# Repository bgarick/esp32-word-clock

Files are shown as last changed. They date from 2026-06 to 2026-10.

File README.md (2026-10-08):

# ESP32 Word Clock

A handmade LED word clock built on an ESP32-C3, displaying time in natural language using 144 NeoPixel LEDs. Mounts vertically or horizontally. Colors shift by season and holiday automatically.

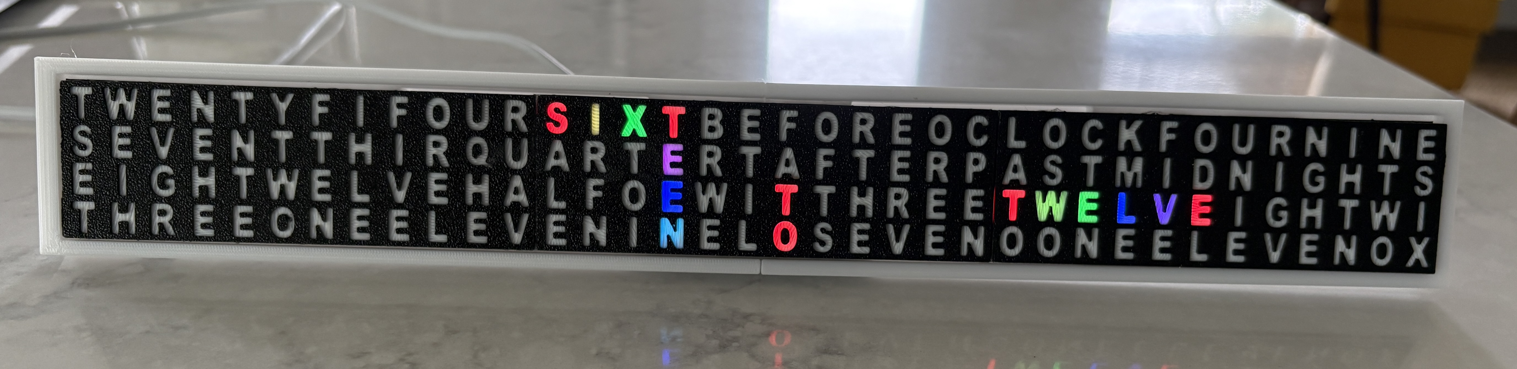
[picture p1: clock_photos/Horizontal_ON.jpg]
Word Clock


---

## How It Works

The clock displays time as words — *"TWENTY FIVE PAST THREE"* — lit across a custom 144-LED grid. The LED layout is unique: every minute of the day is represented by a specific combination of illuminated letters, in two orientations (vertical 4×36, horizontal 36×4) using the same physical LED strip.

Time is synced via NTP over Wi-Fi. Colors change automatically by season, with holiday overrides for Valentine's Day, St. Patrick's Day, July 4th, Halloween, Thanksgiving, and Christmas. June is Pride rainbow. April Fools' Day displays a random wrong time in a random palette every minute.

A configurable birthday date triggers rainbow mode on that day.

---

## Hardware

| Part | Detail |
|---|---|
| Microcontroller | ESP32-C3 Super Mini (no pins soldered — wires direct to board) |
| LED panels | 3× 4×12 NeoPixel panels (WS2812B), chained = 144 LEDs total |
| Data pin | GPIO 4 |
| Button pin | GPIO 9 (BOOT button) |
| Power | 5V via USB-C — standard adapter only, **no quick-charge** |
| 3D printed parts | See STL files in `/stl` |
| Other | Hookup wire, solder, thick clear glue (e.g. Gorilla Glue Clear) |

**Wiring:** 5V → LED 5V, GND → LED GND, GPIO 4 → LED Data In.

**Do not solder header pins to the ESP32-C3.** Solder wires directly into the through-holes. On vertical builds, solder from the back of the board. On horizontal builds, solder from the front.

---

## LED Panels & Addressing

The three 4×12 NeoPixel panels are chained together and addressed by the ESP32-C3 as a single continuous 144-LED array (LED 0–143). No special configuration is needed beyond `NUMPIXELS 144` in the code — the panels are transparent to the firmware.

Each panel has a data-in connector on one end and data-out on the other, with arrows on the PCB showing the LED data flow direction (boustrophedon — snaking back and forth across rows). Chain them so data flows continuously from panel 1 through panel 3.

**LED 0 location:**
- **Vertical:** bottom-right of the assembled clock
- **Horizontal:** top-right of the assembled clock

The mounting clips on the panels must be removed before fitting them into the word panel pockets — they take up too much space. After removing clips, solder the panels together: Data Out of panel 1 → Data In of panel 2, and so on. Solder 5V and GND in parallel across all three panels.

---

## 3D Printed Parts

Each orientation has its own set of STL files.

### Vertical
| File | Description |
|---|---|
| `v_panel_1.stl` | Word panel 1 of 3 |
| `v_panel_2.stl` | Word panel 2 of 3 |
| `v_panel_3.stl` | Word panel 3 of 3 |
| `v_base.stl` | Back panel |

### Horizontal
| File | Description |
|---|---|
| `h_panel_1.stl` | Word panel 1 of 3 |
| `h_panel_2.stl` | Word panel 2 of 3 |
| `h_panel_3.stl` | Word panel 3 of 3 |
| `h_base.stl` | Base panel |
| `h_base_3.stl` | Stand |

The base parts are single-piece designs. If they exceed your printer's build volume, split them in your slicer before printing and glue the pieces together. The horizontal stand (`h_base_3`) attaches to the base with a flat glue joint.

---

## Printing the Word Panels

The word panels are the trickiest part. Each panel has letters on the front face and a grid of LED pockets on the back that the LED panels seat into.

**Print face down** (letters on the bed). No supports needed.

### Color Change Sequence
The panels require two filament color changes:

1. **Black** — letters print first, face down on the bed
2. **White** — flat backing layer; this is the light diffuser that lets LED glow through the letters while blocking bleed between them
3. **Black** — final top layer(s) seal the back and prevent light bleed around the outside

The exact layer numbers depend on your slicer settings and layer height. Preview in your slicer before printing — you're looking for the transition where the letters end, the flat diffuser layer begins, and then the solid back begins. See **clock_photos/Print_Detail.jpg**

The base parts print in black only — no color change needed.

### Glue
Use a thick, non-runny clear adhesive (Gorilla Glue Clear works well). Runny glues will wick into the LED pockets and onto the LEDs. Glue is used for all joints: LED panels into word panel pockets, word panels to each other, word panel assembly to base, and base to stand.

---

## Classic ESP32 (Dev Module) Build

The same source also builds for a classic ESP32 dev board (the original, non-C3 design). The right image is chosen by the board you compile for, and each chip auto-updates from its own binary.

| | ESP32-C3 | Classic ESP32 |
|---|---|---|
| Arduino board | ESP32C3 Dev Module | ESP32 Dev Module |
| LED data pin | GPIO 4 | GPIO 4 (default, selectable) |
| Button pin | GPIO 9 | GPIO 0 (BOOT) |
| Release file | `esp32-word-clock.bin` | `esp32-word-clock-esp32.bin` |

**Easiest install:** open the installer page, click the button for your board, and pick the serial port. A normal install keeps WiFi/timezone settings.

**LED stays dark?** On the classic ESP32 the data pin can be changed without reflashing: hold BOOT while powering on, join the `Word Clock Setup` WiFi network, pick the correct *LED Data Pin*, and save. The clock restarts on the new pin. The picker only offers GPIOs that are safe for NeoPixel data (not flash, input-only, or boot-strapping pins).

**Manual flashing:** the release also includes `esp32-word-clock-esp32-full.bin`, a single merged image to write at address `0x0` with esptool or the Espressif Flash Download Tool.

---

## ESP32-C3 Mounting

The ESP32-C3 sits in a dedicated pocket in the base. **Orient it carefully before gluing** — the BOOT button must align with the access hole and the USB-C port must remain accessible. Once glued there is no repositioning it.

- **Horizontal:** ESP32-C3 pocket is inside the base housing, board tucked in with wires soldered from the front
- **Vertical:** ESP32-C3 pocket is on the outside back of the base, more exposed, with the button hole above it and wires soldered from the back of the board

---

## Test Before You Glue

**Do this before any permanent assembly.**

Wire up the chained LED panels to the ESP32-C3. Flash the included test sketch for your orientation — `Horizontal_Word_Test.ino` or `Vertical_Word_Test.ino`. Each sketch cycles through every defined word, lighting the correct LEDs for one second each and printing the word name and LED indices to Serial.

Verify every word lights up in the right position on the physical panels before proceeding. Once the LED panels are glued into the word panel pockets there is no going back without damage.

---

## Assembly Order

1. **Print word panels** — black/white/black color change, face down, no supports
2. **Print base panels** — black only; split in slicer if needed for your print bed
3. **Prep LED panels** — remove mounting clips, solder panels into a chain, solder leads to ESP32-C3
4. **Test** — flash the appropriate word test sketch, verify all words light up correctly
5. **Seat LEDs** — press LED panels into the pockets on the back of the word panels, glue in place
6. **Join word panels** — glue the three word panels together into a single strip
7. **Mount ESP32-C3** — orient carefully so BOOT button and USB-C align with access points, glue in place
8. **Attach base** — glue base to the back of the word panel assembly
9. **Horizontal only** — glue stand (`h_base_3`) to base with flat joint

---

## Software Setup

### Arduino IDE Board Settings
- Board: **ESP32C3 Dev Module**
- USB CDC On Boot: **Enabled** (required for Serial monitor)

### Libraries Required
- `WiFiManager` (tzapu)
- `Adafruit NeoPixel`
- `Preferences` (built-in ESP32)

### First Upload
1. Clone or download this repo
2. Open `esp32-word-clock.ino` in Arduino IDE
3. Select correct board and port
4. Upload

---

## First-Time Setup

On first power-up the clock broadcasts a Wi-Fi network called **Word Clock Setup**.

1. Connect your phone to **Word Clock Setup** (no password) — see **clock_photos/WiFi_Config.png**
2. The setup portal opens automatically — or go to `192.168.4.1`
3. Select your Wi-Fi network and enter password
4. Choose your **timezone** (US only: Eastern, Central, Mountain, Pacific, Alaska, Hawaii)
5. Choose **layout** (Vertical or Horizontal — must match your physical build)
6. Set your **birthday month/day** for rainbow mode on that date
7. Save — clock restarts and displays correct time within 30 seconds

**2.4 GHz only.** If your router shares a name for both bands, separate them in router settings.

---

## The Setup Button

There's a small hole on the back near the USB-C port. Use a straightened wire to press the button through it.

| Action | Result |
|---|---|
| Press at any time | Reopens setup portal |
| Hold 5 seconds at startup | Clears saved Wi-Fi credentials |

---

## Color Palettes

> Note: Photos in `clock_photos/` were taken in June — colors shown are Pride Month rainbow mode.

| Period / Holiday | Colors |
|---|---|
| Winter (Dec 22 – Mar) | Blues |
| Spring (Mar – Jun) | Pinks, yellows |
| Summer (Jun – Sep 21) | Teals, greens |
| Fall (Sep 22 – Dec 21) | Oranges, reds |
| Valentine's Day (Feb 14) | Pinks, reds |
| St. Patrick's Day (Mar 17) | Greens, gold |
| July 4th | Red, white, blue per letter |
| Halloween (all October) | Orange, purple |
| Thanksgiving | Warm ambers |
| Christmas (all December) | Red, green, gold |
| Pride (all June) | Rainbow per letter |
| Birthday | Rainbow per letter |
| April Fools' | Random wrong time, random palette |

---

## Build Notes & Gotchas

**New ESP32-C3 modules may need a manual reset after first upload.** Code will compile and upload successfully but the clock won't run. If this happens, press RESET on the board after upload completes. If it still doesn't run, hold BOOT, press RESET, release RESET, release BOOT — then upload again and press RESET when done. This may take several attempts on a fresh module. It's a quirk of the C3's USB CDC boot sequence, not a code or wiring problem.

**Test before you glue.** Once the LED panels are glued into the word panel pockets there's no going back without damage. Flash the word test sketch and verify every word first.

**Orient the ESP32-C3 before gluing.** The BOOT button and USB-C port must align with their access points in the base. Dry-fit before committing.

**NeoPixel data chain is fragile.** If only part of your strip lights up after assembly, suspect a broken LED interrupting the data line — not a wiring or code problem. The word test sketch will help isolate exactly where the chain breaks.

**Remove the LED panel clips before fitting.** The mounting clips on the 4×12 panels prevent them from seating into the word panel pockets. Remove them first.

**Use thick glue.** Runny adhesives wick into the LED pockets and onto the LEDs. Use a thick clear adhesive that stays where you put it.

**LED_PIN name collision.** On ESP32-C3, `LED_PIN` is defined by the core. The code uses `#define LED_PIN 4` which overrides it — don't rename it to something the core also defines.

**Layout must match your physical build.** Vertical and horizontal use different LED index maps. Set the correct layout in the portal or the words will be scrambled.

**Power supply matters.** 144 LEDs can draw significant current. Use a decent 5V/2A+ adapter. Quick-charge adapters can cause instability.

**Wi-Fi watchdog.** If the clock loses Wi-Fi for 60 seconds it reboots automatically and reconnects. Normal behavior, not a bug.

**NTP sync on first boot.** The clock tries up to 20 NTP sync attempts. If time is wrong on first boot, open the portal, re-save, and let it retry.

---

## Feedback & Questions

- **Bug or build problem?** Open an [Issue](https://github.com/bgarick/esp32-word-clock/issues)
- **Questions or build logs?** Start a [Discussion](https://github.com/bgarick/esp32-word-clock/discussions)

---

## Repository Structure

```
esp32-word-clock/
├── esp32-word-clock.ino
├── Horizontal_Word_Test.ino
├── Vertical_Word_Test.ino
├── stl/
│   ├── v_panel_1.stl
│   ├── v_panel_2.stl
│   ├── v_panel_3.stl
│   ├── v_base.stl
│   ├── h_panel_1.stl
│   ├── h_panel_2.stl
│   ├── h_panel_3.stl
│   ├── h_base.stl
│   └── h_stand.stl
├── clock_photos/
│   ├── Horizontal_ON.jpg
│   ├── Horizontal_OFF.jpg
│   ├── Vertical_ON.jpg
│   ├── Vertical_OFF.jpg
│   ├── Vertical_Hanger-Hook.jpg
│   ├── Print_Detail.jpg
│   └── WiFi_Config.png
├── README.md
└── LICENSE
```

---

## License

Creative Commons Attribution-NonCommercial-ShareAlike 4.0 International (CC BY-NC-SA 4.0)

© 2026 Bob Garick

**Share and adapt freely for personal, non-commercial use. You must credit the original author and license any derivatives under the same terms. Commercial use is prohibited.**

Full license text: [LICENSE](LICENSE) | https://creativecommons.org/licenses/by-nc-sa/4.0/

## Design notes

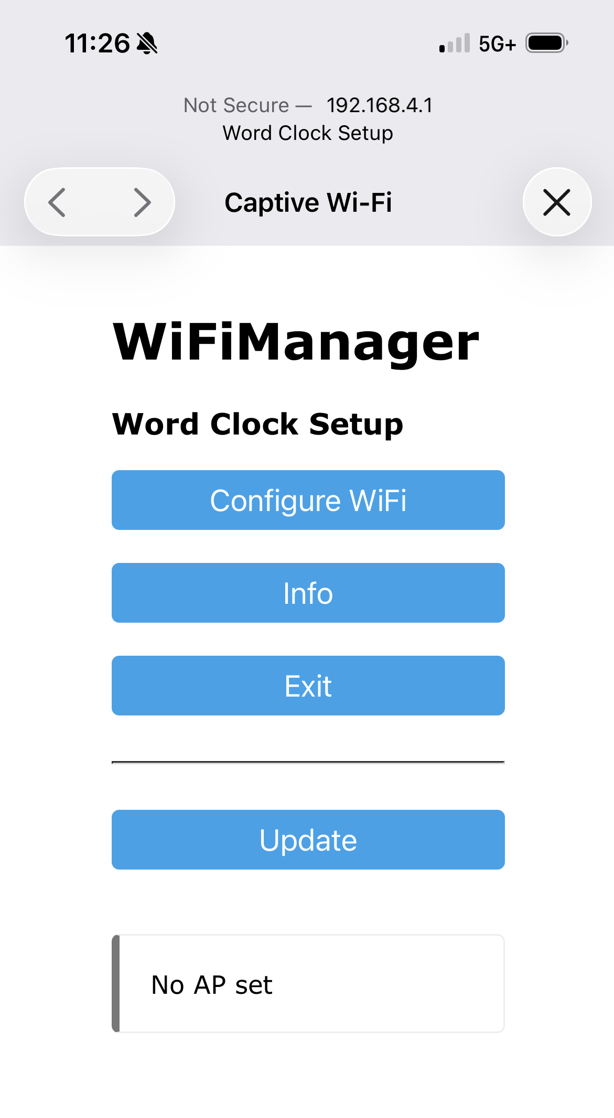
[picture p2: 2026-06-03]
clock_photos/WiFi_Config.PNG

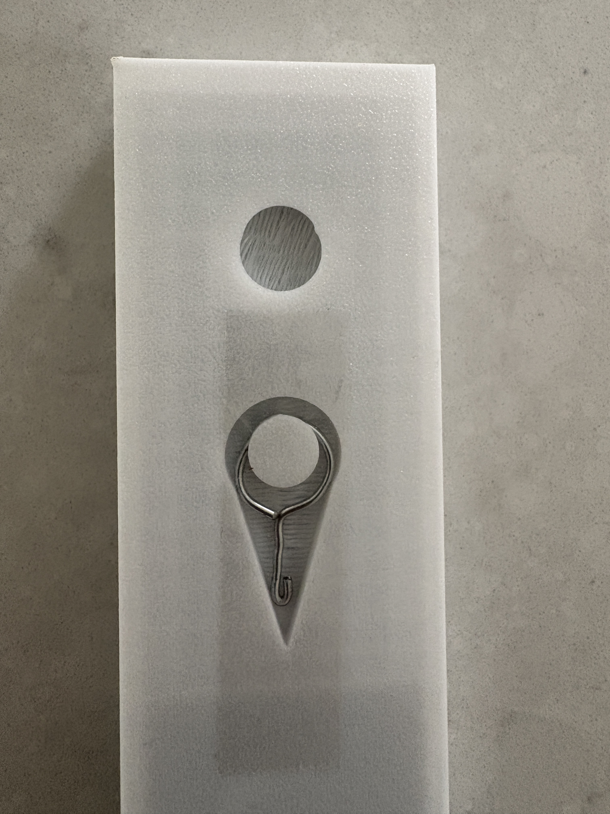
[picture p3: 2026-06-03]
clock_photos/Vertical_Hanger-Hook.JPG

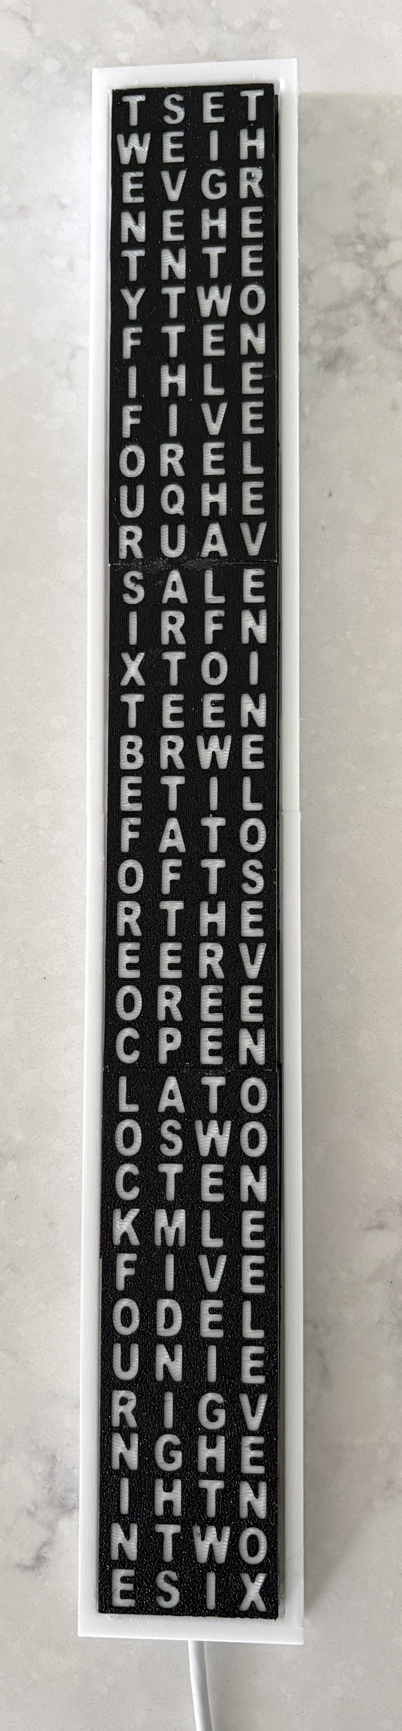
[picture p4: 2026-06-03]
clock_photos/Vertical_OFF.jpg

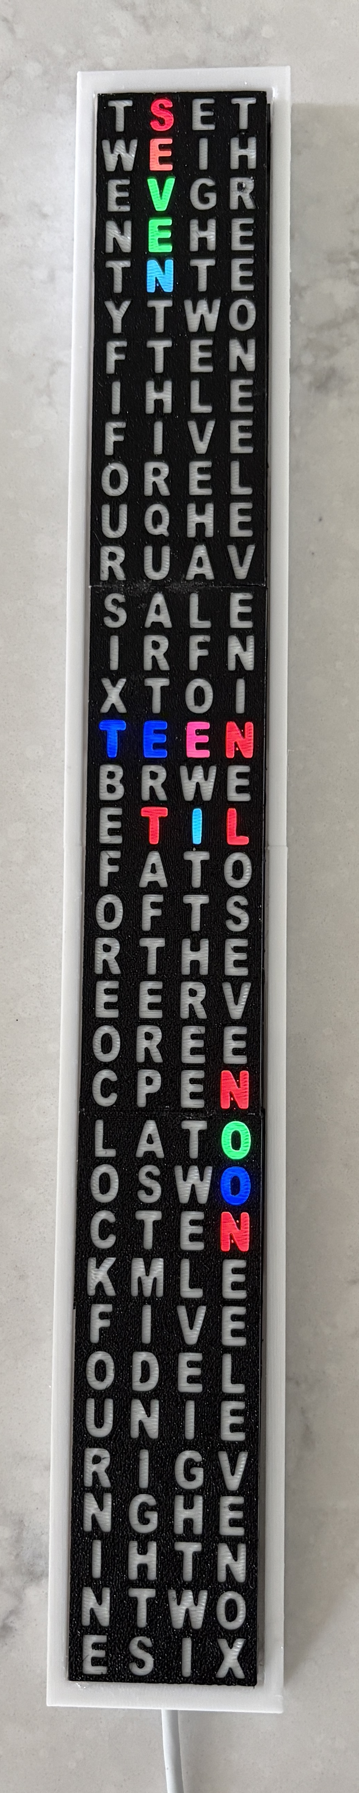
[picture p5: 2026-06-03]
clock_photos/Vertical_ON.jpg

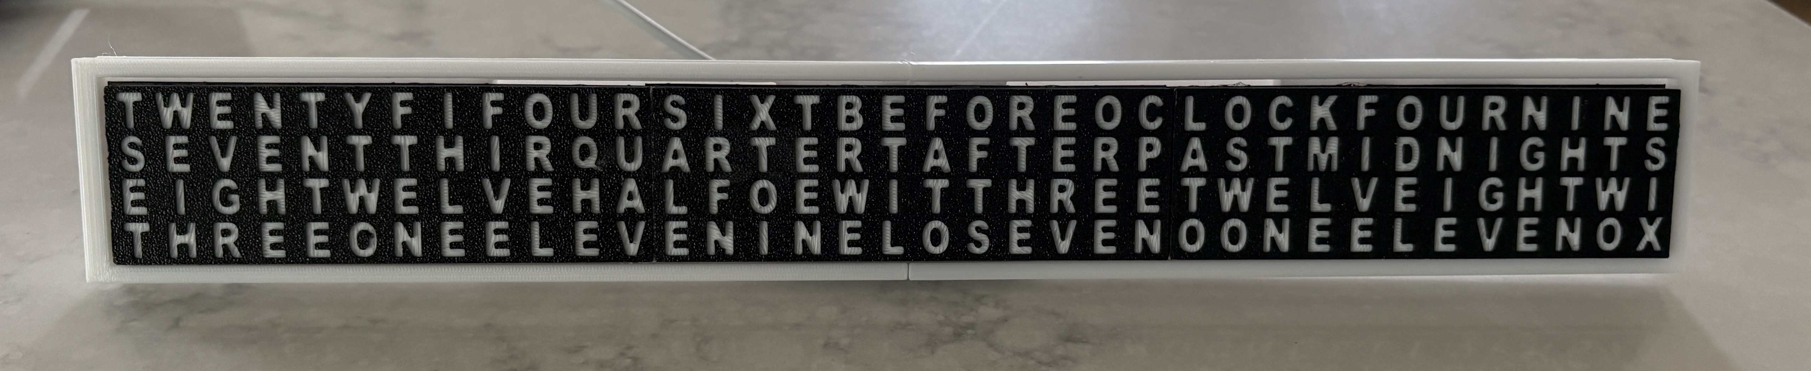
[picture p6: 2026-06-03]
clock_photos/Horizontal_OFF.JPG

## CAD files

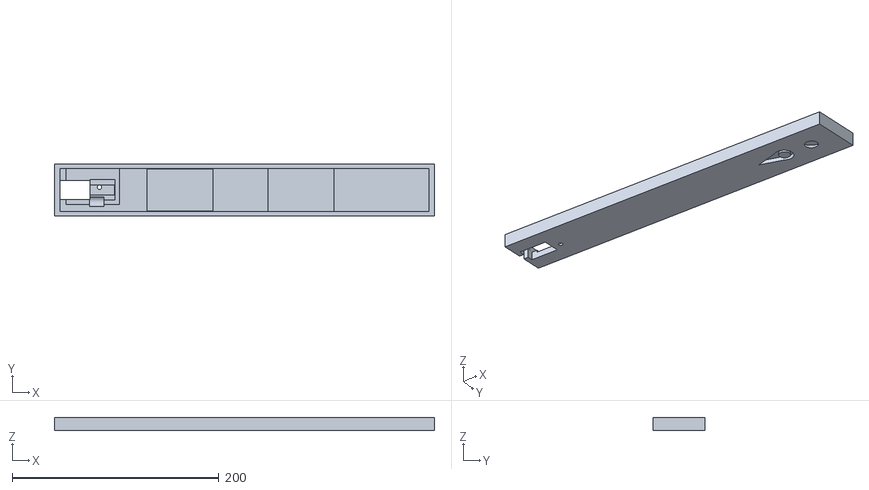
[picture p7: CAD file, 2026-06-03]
stl/v_base.stl
368.0 x 50.0 x 13.0

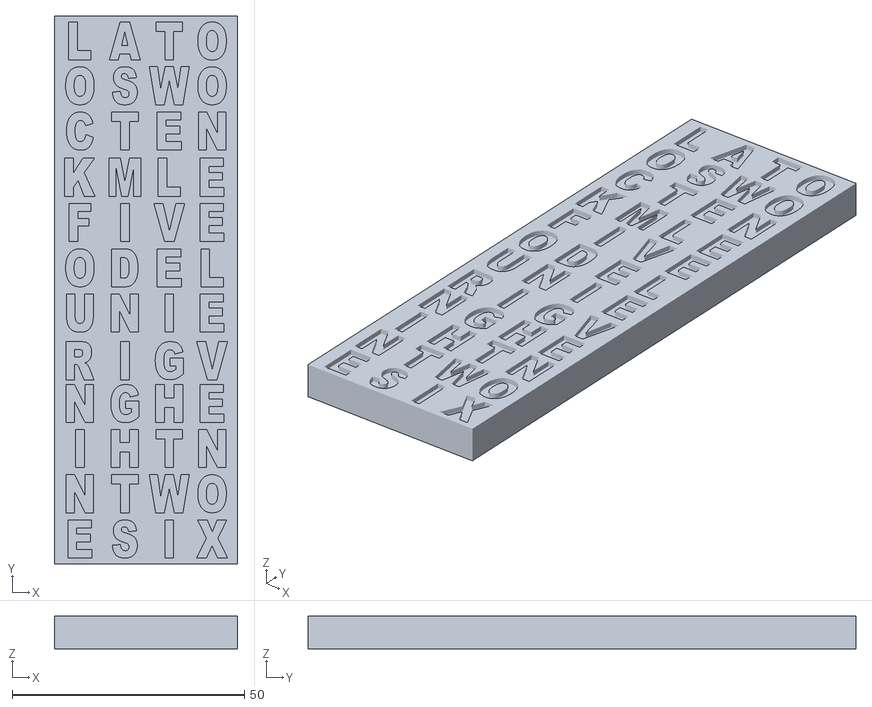
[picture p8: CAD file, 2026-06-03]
stl/v_panel_3.stl
39.5 x 118.0 x 7.00

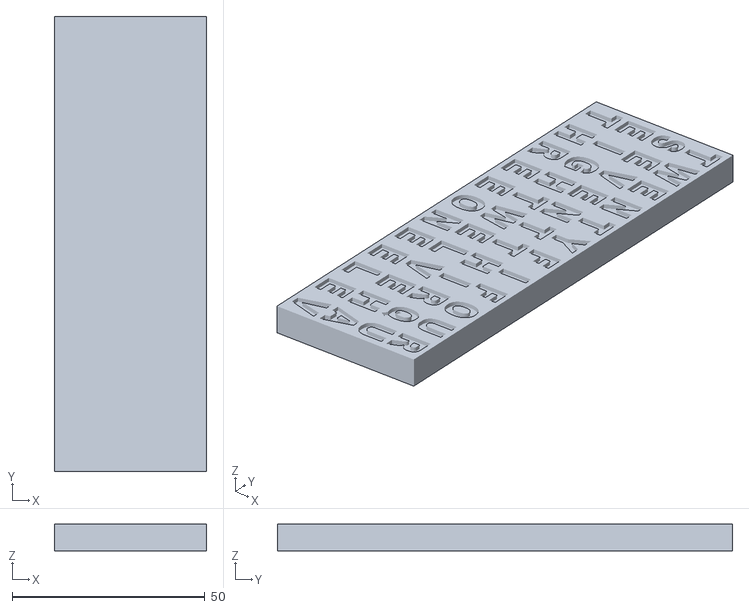
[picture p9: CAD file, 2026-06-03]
stl/h_panel_1.stl
39.5 x 118.0 x 7.00

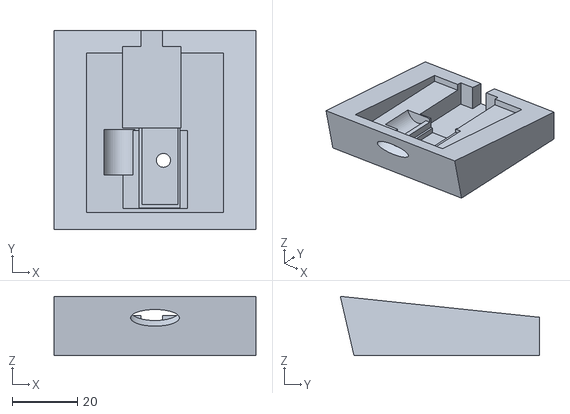
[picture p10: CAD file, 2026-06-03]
stl/h_stand.stl
62.0 x 61.2 x 18.2

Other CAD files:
stl/h_base.stl
stl/h_panel_2.stl
stl/h_panel_3.stl
stl/v_panel_2.stl
stl/v_panel_1.stl

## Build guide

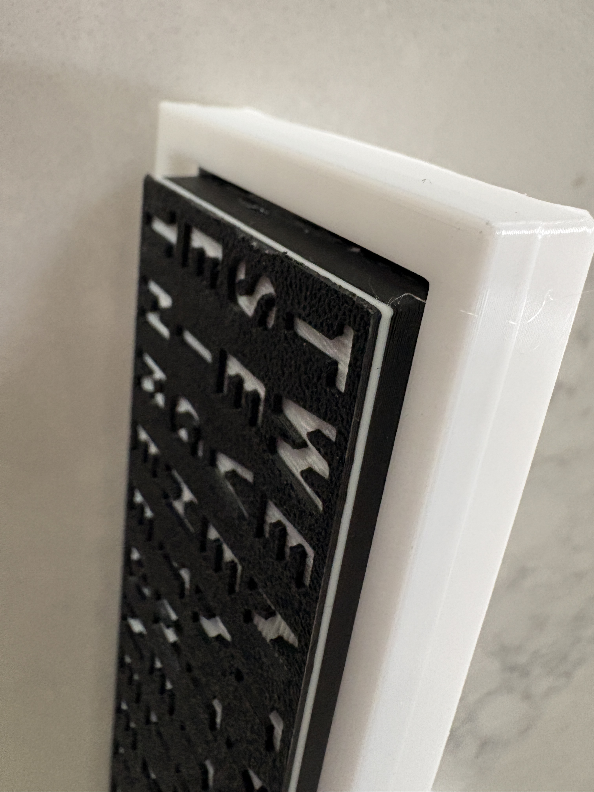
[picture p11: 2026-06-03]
clock_photos/Print_Detail.JPG

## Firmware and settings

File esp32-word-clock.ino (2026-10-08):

/*
  ESP32-C3 Super Mini — Word Clock + WiFiManager (SSID + Timezone + Birthday + Layout)
  With verbose serial debug logging.

  Changes from original ESP32 version:
    - LED_PIN  changed from 13 -> 4   (safe output on C3)
    - BTN_PIN  changed from  0 -> 9   (BOOT button is GPIO9 on C3)
    - Serial startup: delay(1000) + while(!Serial) for native USB CDC
    - Removed esp_wifi_set_ps(WIFI_PS_NONE) — not needed / problematic on C3
    - Kept esp_wifi.h for esp_wifi_restore() only (esp_wifi_connect removed)
    - Board: ESP32C3 Dev Module, USB CDC On Boot: Enabled

  v2 changes:
    - Removed brightness slider; brightness fixed at default (15)
    - Birthday month/day now configurable via portal (saved to Preferences)

  v3 changes:
    - Layout (Vertical / Horizontal) selectable via portal (saved to Preferences)

  v11 changes:
    - One source, two builds. Target is picked at compile time:
        ESP32-C3 (Super Mini)      -> LED GPIO4, button GPIO9, esp32-word-clock.bin
        classic ESP32 (Dev Module) -> LED GPIO4 (selectable in portal), button GPIO0,
                                      esp32-word-clock-esp32.bin
    - Classic ESP32: LED data pin is selectable in the setup portal (safe GPIOs only).
    - OTA downloads the binary that matches the chip it is running on.
*/

#include <WiFi.h>
#include <WiFiManager.h>
#include <DNSServer.h>
#include <WebServer.h>
#include <Preferences.h>
#include <time.h>
#include <Adafruit_NeoPixel.h>
#include <math.h>
#include <esp_wifi.h>
#include <esp_system.h>
#include <string.h>
#include <HTTPClient.h>
#include <WiFiClientSecure.h>
#include <HTTPUpdate.h>
#include <ArduinoJson.h>

#define NUMPIXELS  144
#define DELAYVAL   30000

// ---- Per-chip build target (chosen automatically by the selected board) ----
#if defined(CONFIG_IDF_TARGET_ESP32C3)
  #define BOARD_NAME        "ESP32-C3"
  #define DEFAULT_LED_PIN   4
  #define BTN_PIN           9                          // BOOT button on C3 Super Mini
  #define FW_BIN_NAME       "esp32-word-clock.bin"     // name kept for clocks already in the field
#elif defined(CONFIG_IDF_TARGET_ESP32)
  #define BOARD_NAME        "ESP32"
  #define DEFAULT_LED_PIN   4
  #define BTN_PIN           0                          // BOOT button on classic ESP32 dev boards
  #define FW_BIN_NAME       "esp32-word-clock-esp32.bin"
  #define LED_PIN_SELECTABLE 1                         // pin picker shown in setup portal
#else
  #error "Unsupported chip: build for ESP32-C3 or classic ESP32"
#endif

uint8_t ledPin = DEFAULT_LED_PIN;       // may be overridden from Preferences (classic ESP32 only)
bool    pinChangePending = false;       // set by portal save; triggers a reboot to apply


Adafruit_NeoPixel pixels(NUMPIXELS, DEFAULT_LED_PIN, NEO_GRB + NEO_KHZ800);

Preferences prefs;
const char* ntpServerA = "time.google.com";
const char* ntpServerB = "pool.ntp.org";
const char* ntpServerC = "time.windows.com";

bool   debug   = true;
tm     tm_now;
time_t nowEpoch;
int    year_, month_, day_, hour_, minute_;
int    r = 0, g = 0, b = 0;
uint16_t frameLitCount = 0;
uint8_t brightness = 15;   // fixed default; no longer user-configurable

// ============================================================================
// Fade / transition state  (added 2026-10-03: smooth staggered time changes)
// ============================================================================
#define FADE_OUT_MS 250     // outgoing words fade to black
#define FADE_IN_MS  320     // each incoming group fades up (slower = gentler)
#define FADE_STEPS  20      // interpolation steps per fade
uint8_t live[NUMPIXELS][3]; // colors currently on the strip (final RGB)
uint8_t tgt [NUMPIXELS][3]; // target frame built by showTime()
uint8_t grp [NUMPIXELS];    // per-pixel group: 0=none 1=hour 2=minute 3=connector
uint8_t g_curGroup = 0;     // group currently being painted by setLEDs()

// ============================================================================
// Special Days (1-5): each a date + mode (3 colors or rainbow) + 3 colors.
// Day 1 replaces the old "birthday". On a matching date the clock uses the
// day's look, overriding the seasonal/holiday palette.
// ============================================================================
#define SD_COLORS   0
#define SD_RAINBOW  1
#define NUM_SPECIAL 5
struct SpecialDay { uint8_t month; uint8_t day; uint8_t mode; uint32_t c1, c2, c3; };
SpecialDay special[NUM_SPECIAL];

// NOTE: keep this helper BELOW struct SpecialDay. Arduino auto-generates function
// prototypes above the first function in the file; a function defined earlier than
// the struct breaks every prototype that mentions SpecialDay (classic-ESP32 build only).
#ifdef LED_PIN_SELECTABLE
// Output-capable GPIOs that are not flash pins, input-only pins, or boot-strapping pins.
static const uint8_t LED_PIN_CHOICES[] = {4, 13, 16, 17, 18, 19, 21, 22, 23, 25, 26, 27, 32, 33};
static bool validLedPin(int p) {
  for (uint8_t c : LED_PIN_CHOICES) if (c == p) return true;
  return false;
}
#endif
int g_activeSpecial = -1;   // index of today's special day, or -1

// Layout: 0 = Vertical, 1 = Horizontal
uint8_t layout = 0;

// ============================================================================
// OTA auto-update (added 2026-10-03)
// Bump FW_VERSION with every release. The GitHub Action publishes version.json
// to Pages and the firmware .bin to the latest Release; the clock updates when
// the published version is higher than the one baked in here.
// ============================================================================
#define FW_VERSION 11
const char* OTA_VERSION_URL  = "https://bgarick.github.io/esp32-word-clock/version.json";
// Each chip downloads its own binary (a C3 image will not boot on a classic ESP32 and vice versa).
const char* OTA_FIRMWARE_URL = "https://github.com/bgarick/esp32-word-clock/releases/latest/download/" FW_BIN_NAME;
int  otaLastCheckYday = -1;   // day-of-year of last daily check (avoid repeats)

volatile bool WIFI_OK = false;
volatile uint8_t WIFI_LAST_REASON = 0;

String ssidHtml;

#define JULY4_PER_LETTER   1
#define RAINBOW_PER_LETTER 1

static uint8_t g_forcePalette = 0;
static bool    g_forceRainbow  = false;
static bool    g_forceJuly4    = false;

// ============================================================================
// Word index arrays — Vertical (layout == 0)
// ============================================================================
int V_oneMin[]     = { 123,115,116 };
int V_twoMin[]     = { 121,122,123 };
int V_threeMin[]   = { 140,139,132,131,124 };
int V_fourMin[]    = { 111,104,103,96 };
int V_fiveMin[]    = { 108,109,110,111 };
int V_sixMin[]     = { 95,88,87 };
int V_sevenMin[]   = { 142,137,134,129,126 };
int V_eightMin[]   = { 141,138,133,130,125 };
int V_nineMin[]    = { 91,84,83,76 };
int V_tenMin[]     = { 116,117,118 };
int V_elevenMin[]  = { 108,107,100,99,92,91 };
int V_twelveMin[]  = { 125,122,117,114,109,106 };
int V_thirteen[]   = { 118,113,110,105,80,81,82,83 };
int V_fourteen[]   = { 111,104,103,96,80,81,82,83 };
int V_fifteen[]    = { 119,112,111,80,81,82,83 };
int V_quarter[]    = { 102,97,94,89,86,81,78 };   // FIX 2026-10-03: was {101,98,93,90,85,82,77} (overlapped HALF; shifted one column)
int V_sixteen[]    = { 95,88,87,80,81,82,83 };
int V_seventeen[]  = { 142,137,134,129,126,80,81,82,83 };
int V_eighteen[]   = { 141,138,133,130,80,81,82,83 };
int V_nineteen[]   = { 91,84,76,80,81,82,83 };
int V_twenty[]     = { 143,136,135,128,127,120 };
int V_half_[]      = { 101,98,93,90 };
int V_after[]      = { 70,65,62,57,54 };
int V_past[]       = { 49,46,41,38 };
int V_til[]        = { 73,74,75 };
int V_of[]         = { 64,65 };
int V_to_[]        = { 68,69 };
int V_before[]     = { 79,72,71,64,63,56 };
int V_oneHour[]    = { 43,36,35 };
int V_twoHour[]    = { 4,5,6 };
int V_threeHour[]  = { 66,61,58,53,50 };
int V_fourHour[]   = { 31,24,23,16 };
int V_fiveHour[]   = { 28,29,30,31 };
int V_sixHour[]    = { 1,2,3 };
int V_sevenHour[]  = { 67,60,59,52,51 };
int V_eightHour[]  = { 26,21,18,13,10 };
int V_nineHour[]   = { 15,8,7,0 };
int V_tenHour[]    = { 38,37,36 };
int V_elevenHour[] = { 28,27,20,19,12,11 };
int V_twelveHour[] = { 45,42,37,34,29,26 };
int V_noon[]       = { 51,44,43,36 };
int V_midnight[]   = { 33,30,25,22,17,14,9,6 };
int V_oclock[]     = { 55,48,47,40,39,32 };
int V_wifiAnim[]   = { 5,2,31,30 };
int V_noAnim[]     = { 51,44 };

// ============================================================================
// Word index arrays — Horizontal (layout == 1)
// ============================================================================
int H_oneMin[]     = { 120,119,112 };
int H_twoMin[]     = { 120,121,122 };
int H_threeMin[]   = { 143,136,135,128,127 };
int H_fourMin[]    = { 99,100,107,108 };
int H_fiveMin[]    = { 108,109,110,111 };
int H_sixMin[]     = { 92,91,84 };
int H_sevenMin[]   = { 141,138,133,130,125 };
int H_eightMin[]   = { 142,137,134,129,126 };
int H_nineMin[]    = { 79,80,87,88 };
int H_tenMin[]     = { 117,118,119 };
int H_elevenMin[]  = { 111,104,103,96,95,88 };
int H_twelveMin[]  = { 126,121,118,113,110,105 };
int H_thirteen[]   = { 117,114,109,106,80,81,82,83 };
int H_fourteen[]   = { 99,100,107,108,80,81,82,83 };
int H_fifteen[]    = { 116,115,108,80,81,82,83 };
int H_quarter[]    = { 101,98,93,90,85,82,77 };   // FIX 2026-10-03: was {102,97,94,89,86,81,78} (overlapped HALF; shifted one column)
int H_sixteen[]    = { 92,91,84,80,81,82,83 };
int H_seventeen[]  = { 141,138,133,130,125,80,81,82,83 };
int H_eighteen[]   = { 142,137,134,129,80,81,82,83 };
int H_nineteen[]   = { 79,80,87,88,80,81,82,83 };
int H_twenty[]     = { 140,139,132,131,124,123 };
int H_half_[]      = { 102,97,94,89 };
int H_after[]      = { 69,66,61,58,53 };
int H_past[]       = { 50,45,42,37 };
int H_til[]        = { 72,73,74 };
int H_of[]         = { 66,67 };
int H_to_[]        = { 70,71 };
int H_before[]     = { 76,75,68,67,60,59 };
int H_oneHour[]    = { 40,39,32 };
int H_twoHour[]    = { 5,6,7 };
int H_threeHour[]  = { 65,62,57,54,49 };
int H_fourHour[]   = { 28,27,20,19 };
int H_fiveHour[]   = { 28,29,30,31 };
int H_sixHour[]    = { 0,1,2 };
int H_sevenHour[]  = { 64,63,56,55,48 };
int H_eightHour[]  = { 25,22,17,14,9 };
int H_nineHour[]   = { 12,11,4,3 };
int H_tenHour[]    = { 39,38,37 };
int H_elevenHour[] = { 31,24,23,16,15,8 };
int H_twelveHour[] = { 46,41,38,33,30,25 };
int H_noon[]       = { 48,47,40,39 };
int H_midnight[]   = { 34,29,26,21,18,13,10,5 };
int H_oclock[]     = { 52,51,44,43,36,35 };
int H_wifiAnim[]   = { 78,73,28,29 };
int H_noAnim[]     = { 48,47 };

// ============================================================================
// Active pointers — set by applyLayout()
// ============================================================================
int* oneMin;
int* twoMin;
int* threeMin;
int* fourMin;
int* fiveMin;
int* sixMin;
int* sevenMin;
int* eightMin;
int* nineMin;
int* tenMin;
int* elevenMin;
int* twelveMin;
int* thirteen;
int* fourteen;
int* fifteen;
int* quarter;
int* sixteen;
int* seventeen;
int* eighteen;
int* nineteen;
int* twenty;
int* half_;
int* after;
int* past;
int* til;
int* of;
int* to_;
int* before;
int* oneHour;
int* twoHour;
int* threeHour;
int* fourHour;
int* fiveHour;
int* sixHour;
int* sevenHour;
int* eightHour;
int* nineHour;
int* tenHour;
int* elevenHour;
int* twelveHour;
int* noon;
int* midnight;
int* oclock;
int* wifiAnim;
int* noAnim;

// Word lengths — same for both layouts
const int LEN_oneMin     = 3;
const int LEN_twoMin     = 3;
const int LEN_threeMin   = 5;
const int LEN_fourMin    = 4;
const int LEN_fiveMin    = 4;
const int LEN_sixMin     = 3;
const int LEN_sevenMin   = 5;
const int LEN_eightMin   = 5;
const int LEN_nineMin    = 4;
const int LEN_tenMin     = 3;
const int LEN_elevenMin  = 6;
const int LEN_twelveMin  = 6;
const int LEN_thirteen   = 8;
const int LEN_fourteen   = 8;
const int LEN_fifteen    = 7;
const int LEN_quarter    = 7;
const int LEN_sixteen    = 7;
const int LEN_seventeen  = 9;
const int LEN_eighteen   = 8;
const int LEN_nineteen   = 8;
const int LEN_twenty     = 6;
const int LEN_half_      = 4;
const int LEN_after      = 5;
const int LEN_past       = 4;
const int LEN_til        = 3;
const int LEN_of         = 2;
const int LEN_to_        = 2;
const int LEN_before     = 6;
const int LEN_oneHour    = 3;
const int LEN_twoHour    = 3;
const int LEN_threeHour  = 5;
const int LEN_fourHour   = 4;
const int LEN_fiveHour   = 4;
const int LEN_sixHour    = 3;
const int LEN_sevenHour  = 5;
const int LEN_eightHour  = 5;
const int LEN_nineHour   = 4;
const int LEN_tenHour    = 3;
const int LEN_elevenHour = 6;
const int LEN_twelveHour = 6;
const int LEN_noon       = 4;
const int LEN_midnight   = 8;
const int LEN_oclock     = 6;
const int LEN_wifiAnim   = 4;
const int LEN_noAnim     = 2;
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
void loop() {
  static int lastMinute = -1;

  static uint32_t wifiLostAt = 0;
  if (!WIFI_OK) {
    if (wifiLostAt == 0) {
      wifiLostAt = millis();
      Serial.println("[WIFI] Connection lost -- watchdog started (60s to restart).");
    }
    if (millis() - wifiLostAt > 60000) {
      Serial.println("[WIFI] Did not recover in 60s -- restarting.");
      ESP.restart();
    }
  } else {
    if (wifiLostAt != 0) {
      Serial.println("[WIFI] Reconnected successfully.");
      wifiLostAt = 0;
    }
  }

  static uint32_t lastBtnCheck = 0;
  uint32_t nowMs = millis();
  if (nowMs - lastBtnCheck > 100) {
    lastBtnCheck = nowMs;
    if (digitalRead(BTN_PIN) == LOW) {
      Serial.println("[BTN] Button pressed -- reopening portal.");
      WiFiManager wm;
      wm.setConfigPortalBlocking(true);
      if (!wm.autoConnect("Word Clock Setup")) {
        Serial.println("[BTN] Portal closed without connection -- keeping prior Wi-Fi.");
      } else {
        Serial.println("[BTN] Portal saved new settings.");
        prefs.begin("settings", true);
        String timezone = prefs.getString("tz", "EST5EDT,M3.2.0/2,M11.1.0/2");
        layout    = prefs.getUChar("layout",    layout);
        loadSpecialDays();
        prefs.end();
        if (layout > 1) layout = 0;
        applyLayout();
        Serial.printf("[BTN] Applied TZ: %s  SpecialDay1: %02u/%02u  Layout: %s\n",
          timezone.c_str(), special[0].month, special[0].day,
          layout == 0 ? "Vertical" : "Horizontal");
        applyTimezone(timezone.c_str());
        ensureTimeSynced();
        lastMinute = -1;
      }
    }
  }

  nowEpoch = time(nullptr);
  localtime_r(&nowEpoch, &tm_now);

  if (tm_now.tm_min != lastMinute) {
    lastMinute = tm_now.tm_min;
    year_   = tm_now.tm_year + 1900;
    month_  = tm_now.tm_mon + 1;
    day_    = tm_now.tm_mday;
    hour_   = tm_now.tm_hour;
    minute_ = tm_now.tm_min;

    // Daily OTA check at ~4am local (once per calendar day)
    if (hour_ == 4 && tm_now.tm_yday != otaLastCheckYday) {
      otaLastCheckYday = tm_now.tm_yday;
      checkForUpdate("daily");
    }

    int dispHour = hour_;
    int dispMin  = minute_;
    g_forcePalette = 0; g_forceRainbow = false; g_forceJuly4 = false;

    if (isAprilFools()) {
      dispHour = random(0, 24);
      dispMin  = random(0, 60);
      uint8_t pick = random(0, 11);
      switch (pick) {
        case 0: g_forcePalette = 1; break;
        case 1: g_forcePalette = 2; break;
        case 2: g_forcePalette = 3; break;
        case 3: g_forcePalette = 4; break;
        case 4: g_forcePalette = 5; break;
        case 5: g_forcePalette = 6; break;
        case 6: g_forcePalette = 7; break;
        case 7: g_forcePalette = 8; break;
        case 8: g_forcePalette = 9; break;
        case 9: g_forceRainbow = true; break;
        case 10:g_forceJuly4   = true; break;
      }
      Serial.printf("[APRILFOOLS] real=%02d:%02d disp=%02d:%02d palette=%u rb=%d j4=%d\n",
        hour_, minute_, dispHour, dispMin,
        g_forcePalette, (int)g_forceRainbow, (int)g_forceJuly4);
    }

    Serial.printf("[CLOCK] %02d/%02d/%04d  real=%02d:%02d  disp=%02d:%02d  palette=%u rainbow=%d july4=%d\n",
      month_, day_, year_, hour_, minute_, dispHour, dispMin,
      g_forcePalette, (int)g_forceRainbow, (int)g_forceJuly4);

    transitionToTime(dispHour, dispMin);   // smooth staggered fade (replaces clear/showTime/power-limit)

    Serial.printf("[CLOCK] Frame done. LEDs lit: %u  Brightness: %u\n",
      frameLitCount, pixels.getBrightness());
  }

  delay(200);
}

// ============================================================================
// Time helpers
// ============================================================================
void applyTimezone(const char* tz) {
  if (!tz || !*tz) tz = "EST5EDT,M3.2.0/2,M11.1.0/2";
  setenv("TZ", tz, 1);
  tzset();
  configTzTime(tz, ntpServerA, ntpServerB, ntpServerC);
  Serial.printf("[TZ] Applied: %s\n", tz);
}

void ensureTimeSynced() {
  Serial.println("[NTP] Waiting for time sync...");
  struct tm ti{};
  int attempts = 0;
  while (!getLocalTime(&ti, 1000) && attempts < 20) {
    Serial.printf("[NTP] Attempt %d/20...\n", attempts + 1);
    int idx = wifiAnim[attempts % LEN_wifiAnim];
    pixels.clear();
    if (idx >= 0 && idx < NUMPIXELS) {
      pixels.setPixelColor(idx, pixels.Color(40, 40, 40));
    }
    pixels.show();
    attempts++;
  }
  pixels.clear();
  pixels.show();
  if (attempts < 20) {
    Serial.printf("[NTP] Synced after %d attempt(s): %02d:%02d:%02d on %02d/%02d/%04d\n",
      attempts + 1, ti.tm_hour, ti.tm_min, ti.tm_sec,
      ti.tm_mon + 1, ti.tm_mday, ti.tm_year + 1900);
  } else {
    Serial.println("[NTP] WARNING: Sync timed out after 20 attempts. Time may be wrong.");
  }
}

// ============================================================================
// Colors
// ============================================================================
void setColor(int order) {
  g_curGroup = (order==1) ? 1 : (order==2) ? 2 : (order==3) ? 3 : 0;  // tag pixels for staggered fade
  if (g_forcePalette) {
    switch (g_forcePalette) {
      case 1: switch(order){ case 1: r=240; g= 90; b=110; break; case 2: r=245; g=185; b= 60; break; case 3: r=255; g=235; b=140; break; default: r=g=b=150; } return;
      case 2: switch(order){ case 1: r=120; g=210; b=230; break; case 2: r= 30; g=150; b= 85; break; case 3: r=255; g=190; b=220; break; default: r=g=b=150; } return;
      case 3: switch(order){ case 1: r=220; g=110; b= 40; break; case 2: r=180; g= 60; b= 30; break; case 3: r=235; g=200; b=120; break; default: r=g=b=150; } return;
      case 4: switch(order){ case 1: r=160; g=210; b=255; break; case 2: r=100; g=140; b=170; break; case 3: r= 40; g= 70; b=140; break; default: r=g=b=150; } return;
      case 5: switch(order){ case 1: r=220; g= 40; b= 80; break; case 2: r=255; g=160; b=200; break; case 3: r=255; g=240; b=245; break; default: r=g=b=150; } return;
      case 6: switch(order){ case 1: r= 20; g=120; b= 60; break; case 2: r= 80; g=170; b= 90; break; case 3: r=230; g=170; b= 40; break; default: r=g=b=150; } return;
      case 7: switch(order){ case 1: r=255; g=120; b=  0; break; case 2: r=110; g= 60; b=150; break; case 3: r=255; g=255; b=255; break; default: r=g=b=150; } return;
      case 8: switch(order){ case 1: r=220; g=110; b= 40; break; case 2: r=140; g= 80; b= 30; break; case 3: r=235; g=200; b=120; break; default: r=g=b=150; } return;
      case 9: switch(order){ case 1: r=200; g= 30; b= 30; break; case 2: r= 20; g=120; b= 60; break; case 3: r=255; g=230; b=120; break; default: r=g=b=150; } return;
    }
  }
  // Special day (highest priority after the April-Fools gag), 3-color mode
  if (g_activeSpecial >= 0 && special[g_activeSpecial].mode == SD_COLORS) {
    uint32_t c = (order == 1) ? special[g_activeSpecial].c1
               : (order == 2) ? special[g_activeSpecial].c2
               : (order == 3) ? special[g_activeSpecial].c3 : 0x969696;
    uint8_t rr, gg, bb; unpack(c, rr, gg, bb);
    r = rr; g = gg; b = bb; return;
  }
  if (isValentine())   { switch(order){ case 1: r=220; g= 40; b= 80; break; case 2: r=255; g=160; b=200; break; case 3: r=255; g=240; b=245; break; default: r=g=b=150; } return; }
  if (isStPatrick())   { switch(order){ case 1: r= 20; g=120; b= 60; break; case 2: r= 80; g=170; b= 90; break; case 3: r=230; g=170; b= 40; break; default: r=g=b=150; } return; }
  if (isHalloween())   { switch(order){ case 1: r=255; g=120; b=  0; break; case 2: r=110; g= 60; b=150; break; case 3: r= 80; g= 80; b= 80; break; default: r=g=b=150; } return; }
  if (isThanksgiving()){ switch(order){ case 1: r=220; g=110; b= 40; break; case 2: r=140; g= 80; b= 30; break; case 3: r=235; g=200; b=120; break; default: r=g=b=150; } return; }
  if (isChristmas())   { switch(order){ case 1: r=200; g= 30; b= 30; break; case 2: r= 20; g=120; b= 60; break; case 3: r=255; g=230; b=120; break; default: r=g=b=150; } return; }
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

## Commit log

2026-10-03 Add OTA auto-update, staggered fade, and QUARTER fix
    - QUARTER corrected in both layouts (was overlapping HALF; shifted one column)
    - Smooth staggered time transition: outgoing words fade to black, then
    connector -> minute -> hour fade in; unchanged hour stays lit
    - OTA: FW_VERSION + daily/boot check of version.json on GitHub Pages,
    self-update from the latest GitHub Release (HTTPUpdate, two-slot, settings preserved)
    - GitHub Action compiles the ESP32-C3 bin, cuts the Release, and deploys the
    ESP Web Tools install page + version.json to Pages
    - docs/: browser-based installer (ESP Web Tools) for the one-time USB bootstrap
    Claude-S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
    [esp32-word-clock.ino]
2026-10-04 Special Days (5) with per-day color/rainbow; PR compile checks
    - Replace single Birthday with 5 configurable Special Days (date + mode +
    3 colors). Day 1 migrates the existing birthday; defaults to rainbow.
    - Per day: 3 Colors (hour/minute/connector) OR Rainbow, chosen in the portal
    with native color pickers; show/hide colors by mode.
    - Special day overrides seasonal/built-in holiday looks on matching dates.
    - Stored as 5 CSV strings in NVS (sd1..sd5); settings preserved across OTA.
    - FW_VERSION -> 9.
    - CI: add pull_request trigger that compiles only (release/Pages gated to
    push/main), so PRs are validated before merge.
    Claude-Se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
    [esp32-word-clock.ino]
2026-10-05 Special-days color UI, fade order + top-of-hour, slower fade-in (v10)
    - Color pickers always visible and labeled Hour/Minute/Word; dimmed (not hidden)
    in Rainbow mode, so colors are discoverable on every day incl. Day 1.
    - Fade-in order minute -> connector -> hour (reading order).
    - Top of the hour fades HOUR first, then O'CLOCK.
    - Slower fade-in: FADE_IN_MS 200 -> 320.
    - FW_VERSION -> 10.
    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
2026-10-08 Add classic ESP32 build with selectable LED pin and per-chip OTA
    One source now builds for ESP32-C3 and classic ESP32 (chosen by board target).
    - Classic ESP32: BTN GPIO0, LED GPIO4 by default, LED pin selectable in the
    setup portal from a whitelist of safe GPIOs (reboots to apply)
    - OTA fetches the binary matching the running chip; C3 filename unchanged
    - CI compiles both targets and attaches both .bin files to the release
    - New ESP Web Tools manifest (chipFamily ESP32, bootloader at 0x1000)
    - Installer page offers both boards
    - FW_VERSION 10 -> 11
    Claude-Session: https://claude.ai/code/session_01NVQ2A1LUbvRhUmNK4Zmqyj
    [esp32-word-clock.ino]
2026-10-08 README: document classic ESP32 build and LED pin selection
    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
2026-10-08 CI: surface classic ESP32 compiler errors as annotations
    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
2026-10-08 Fix classic build: define validLedPin after struct SpecialDay
    Auto-generated prototypes are inserted above the first function; having it
    first put them ahead of SpecialDay and broke compilation on the classic target.
    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
    [esp32-word-clock.ino]
2026-10-28 Make the firmware ESP32-C3 only; classic ESP32 moves to its own repo
    No behavior change on the C3. FW_VERSION stays 11.
    - Removed classic target, LED pin picker, and pin-change reboot code
    - Removed classic compile/assemble/release steps and manifest-esp32.json
    - Installer page points classic users to esp32-word-clock-classic
    - README: classic section replaced with a pointer
    Claude-Session: https://claude.ai/code/session_01DnVCVshkdHSn9ST3Cc67TL
2026-10-28 Add 16x8 crossword and 12x12 square layouts (v12)
    - Layout 2: 16x8 crossword (two 8x8 panels, same wiring pattern on both;
    lower = LEDs 0-63, upper = 64-127). Map and all 40 words verified on hardware.
    - Layout 3: 12x12 square from square_v7 (not yet verified on hardware).
    - Layouts 0/1 unchanged; connector words picked only from words the layout has.
    - C3 Wi-Fi TX power capped at 8.5 dBm; saved-WiFi wait 12 s -> 30 s.
    - Per-layout brightness (16x8 = 75, others 15).
    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
2026-10-28 Fix portal save clamping the layout to Vertical/Horizontal only
    The setup-portal save callback limited the layout to 0..1, so choosing
    Crossword (2) or Square (3) silently saved Vertical. Allow 0..3.
    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
2026-11-11 v13: brightness slider, BOOT-hold setup, WIFI/CLOCK letter animations, live previews
    - Brightness slider back in setup (5-100, default 15 on every layout); live preview while dragging
    - Hold BOOT ~0.5 s on a running clock to open setup; WiFi and settings kept; Save closes setup ~3 s later
    - WIFI letters light one at a time while joining WiFi / in setup; CLOCK letters while waiting for NTP
    - Layout dropdown previews on the plate; closing without Save restores the saved layout
    - Default layout is now 16x8 Crossword
    - Boot WiFi join: all-channel scan, strongest AP, retry every 10 s, failure reasons logged in words
    - Removed the WiFi dropdown; added a "Keep current WiFi" checkbox for BOOT-hold s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
